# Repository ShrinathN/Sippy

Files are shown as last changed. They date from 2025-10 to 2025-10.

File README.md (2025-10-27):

# Sippy
A device which will remind me to drink water. Pretty cool. Uses accelerometer data to predict when, and how much water was drank. Needs the geometry of the bottle it is mounted on to work. WIP.

## Assembled
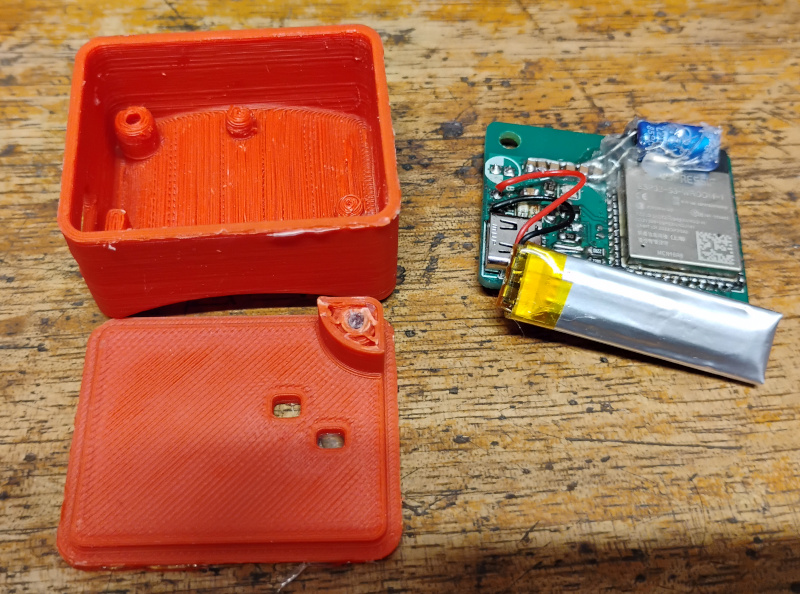
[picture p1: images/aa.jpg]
device

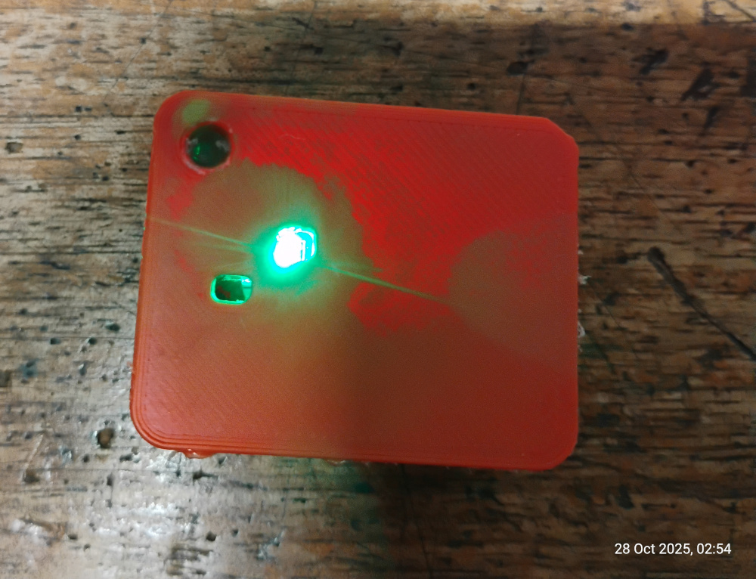
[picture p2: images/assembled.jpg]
assem

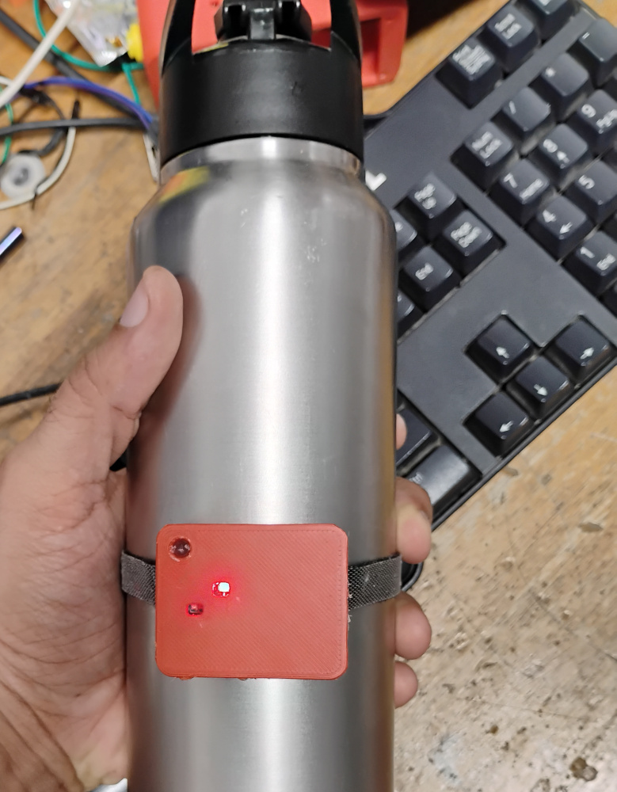
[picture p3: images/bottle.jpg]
bottle


## Images of the board
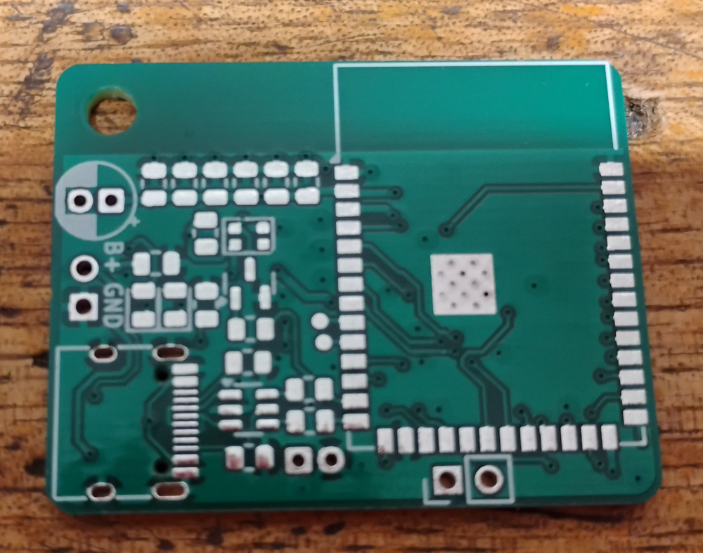
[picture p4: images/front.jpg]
front

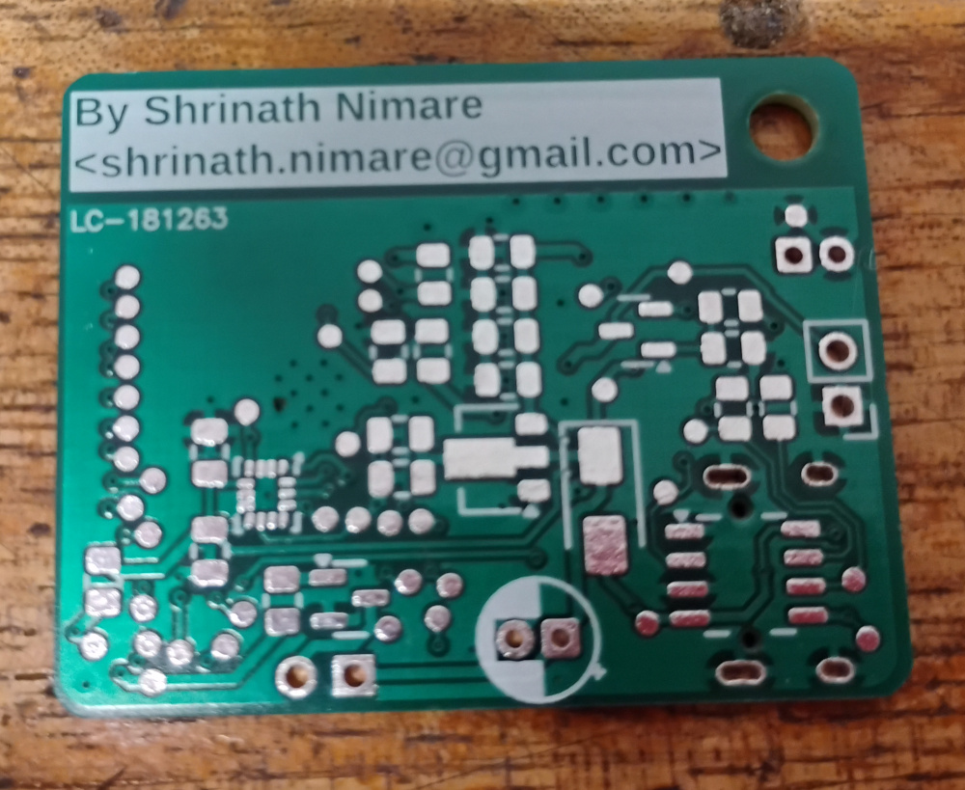
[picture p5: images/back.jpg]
back


## Images of the enclosure
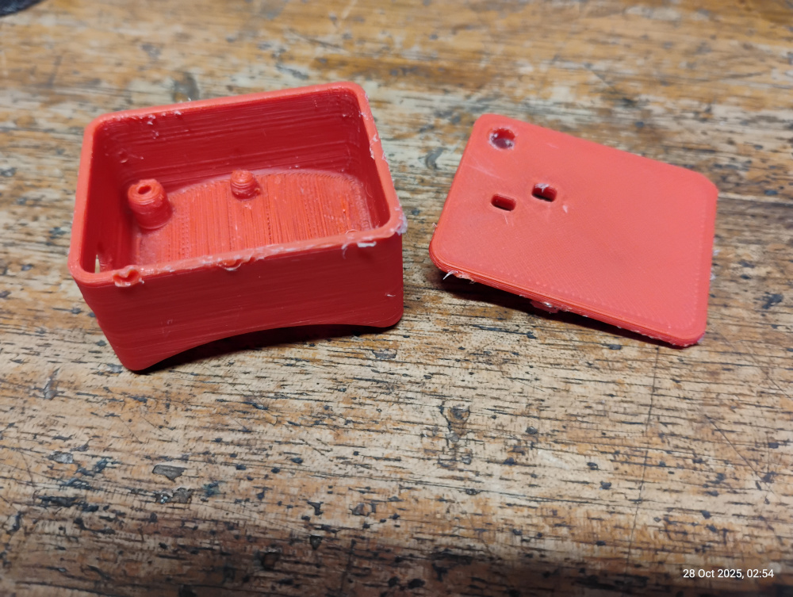
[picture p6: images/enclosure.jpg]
enclosure1

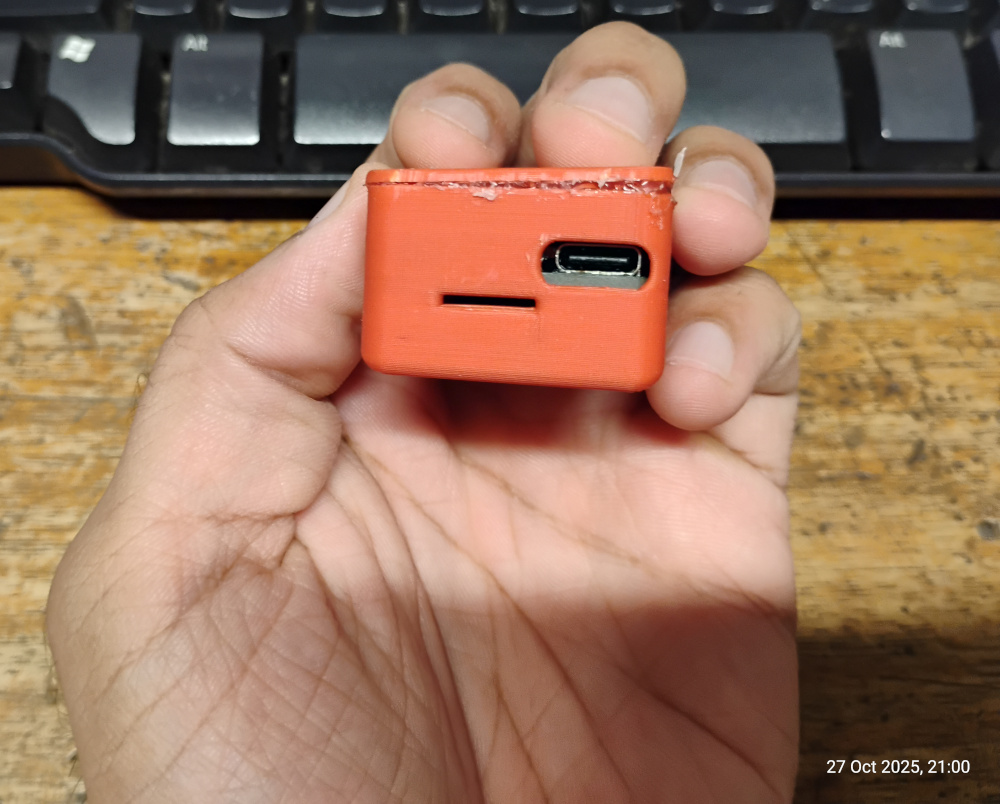
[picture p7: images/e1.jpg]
enclosure2

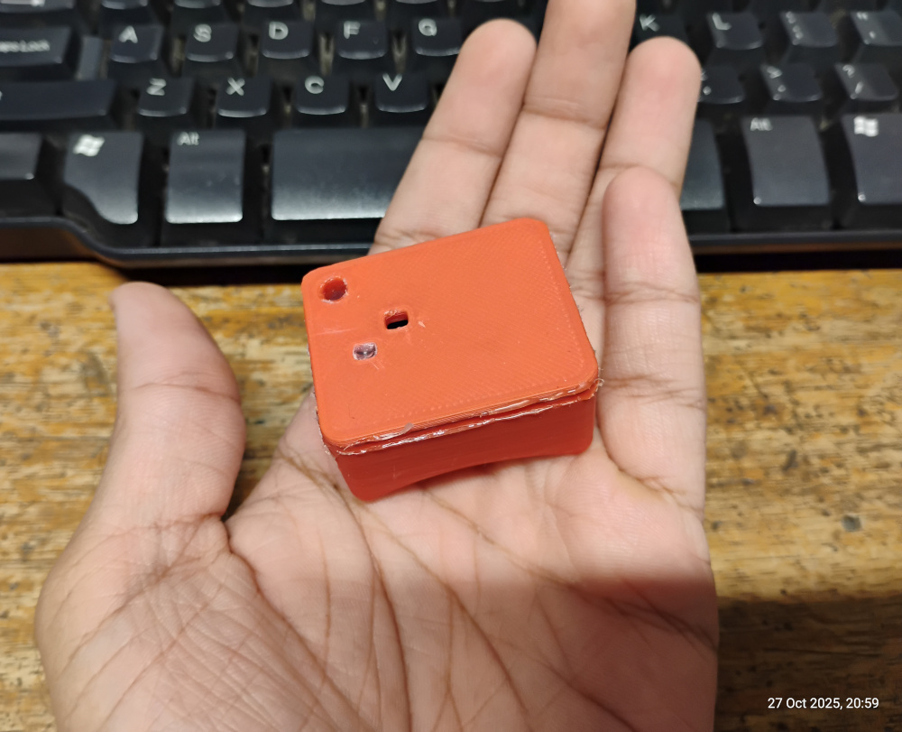
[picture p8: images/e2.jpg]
enclosure3


## Renders of the PCB
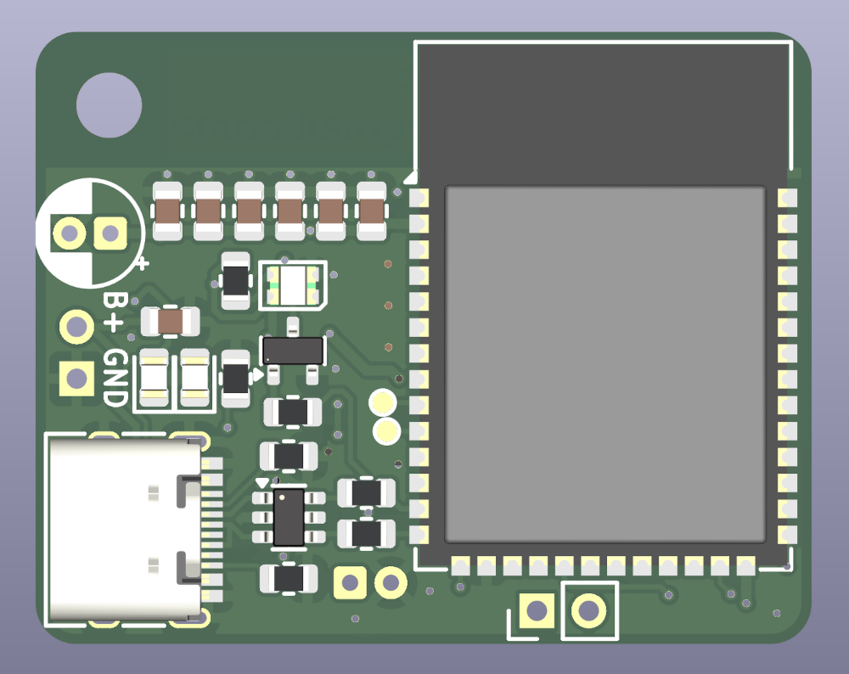
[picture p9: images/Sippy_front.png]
front

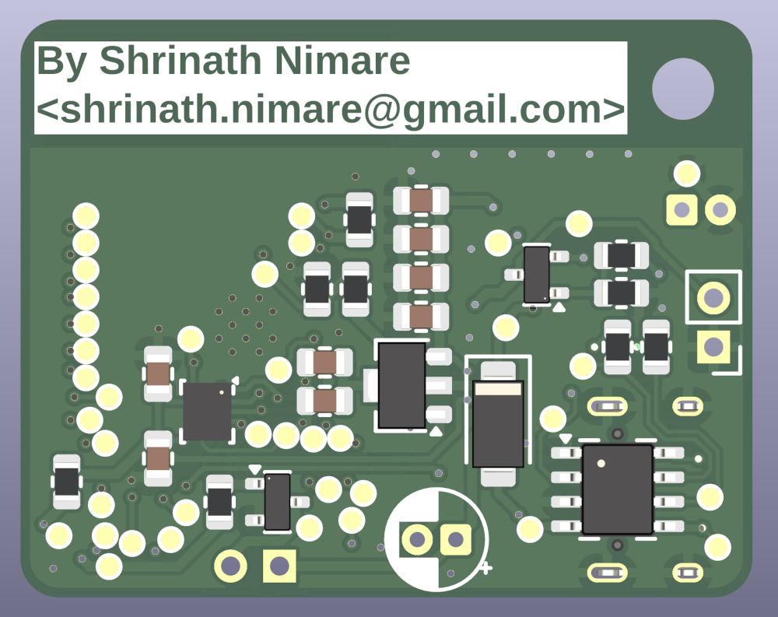
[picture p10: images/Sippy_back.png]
back


## Renders of the enclosure
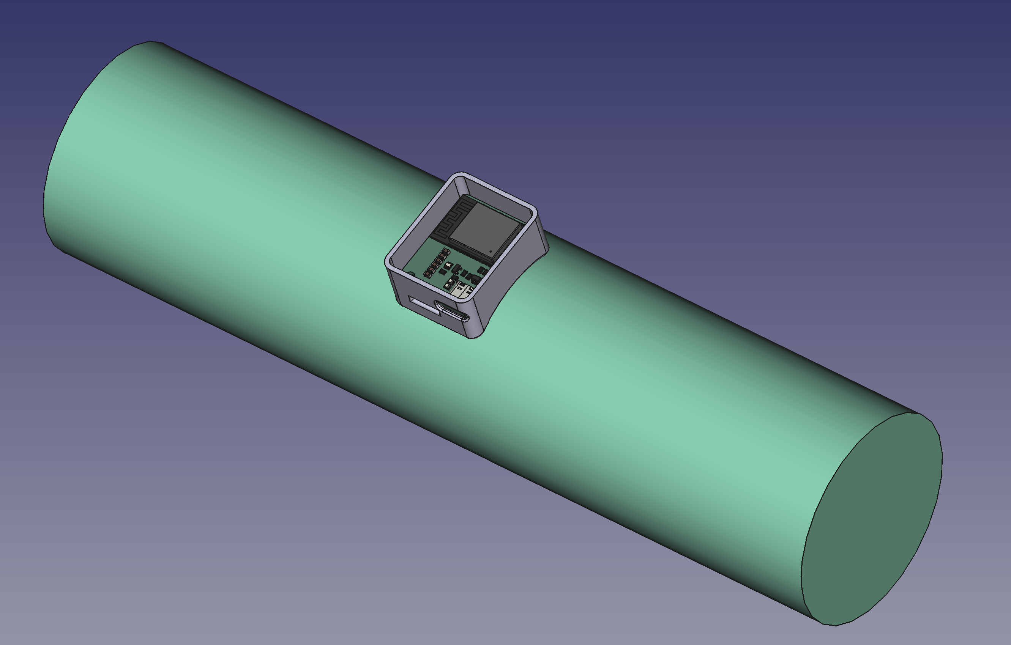
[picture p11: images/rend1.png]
rend1

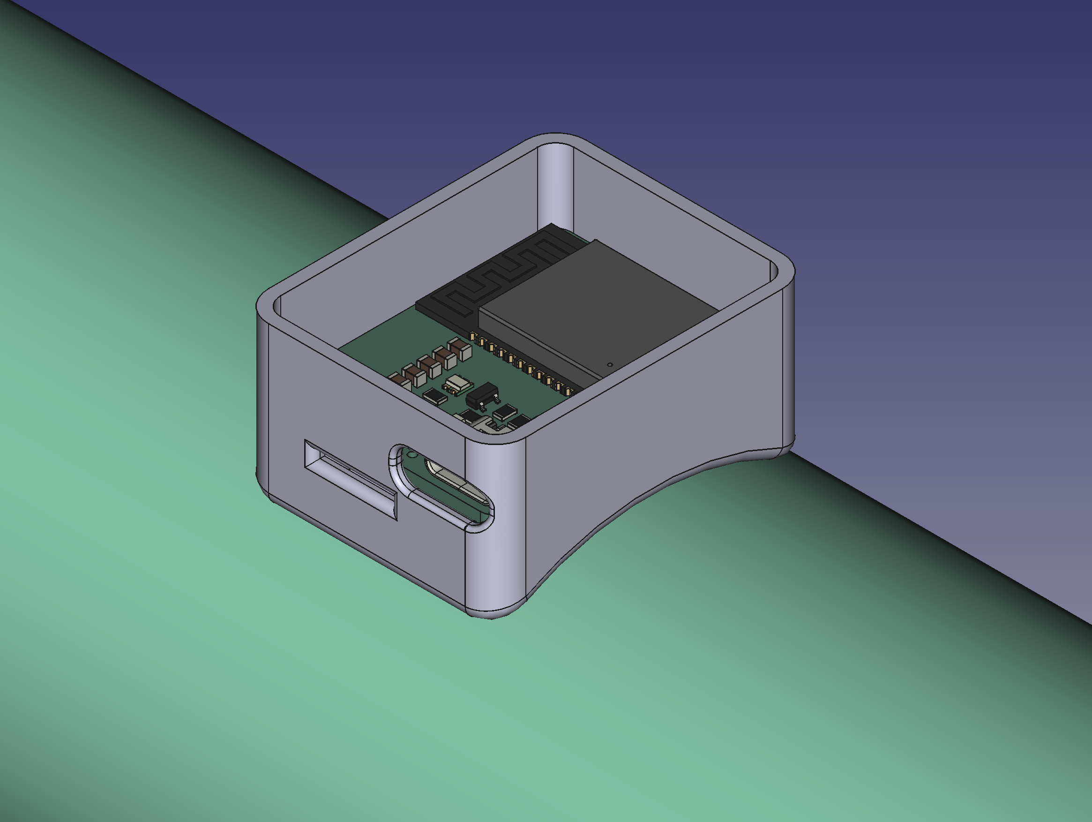
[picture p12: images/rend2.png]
rend2

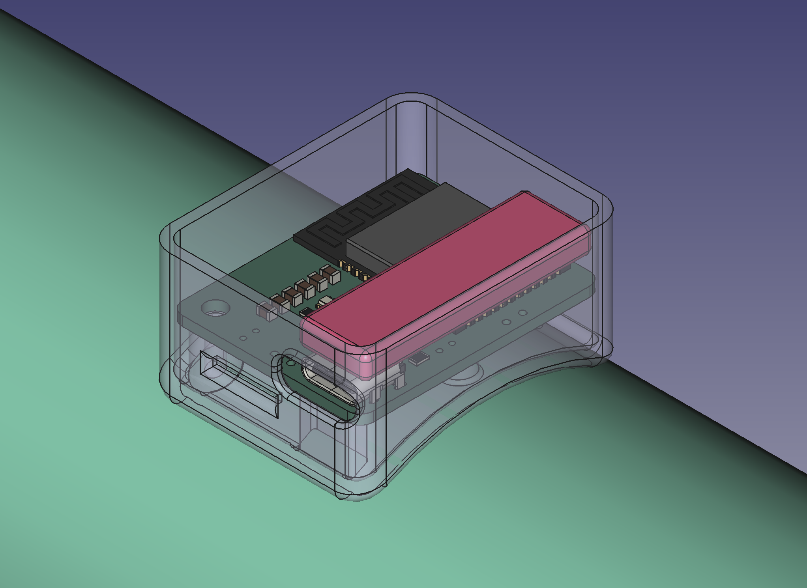
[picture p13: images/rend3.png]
rend3

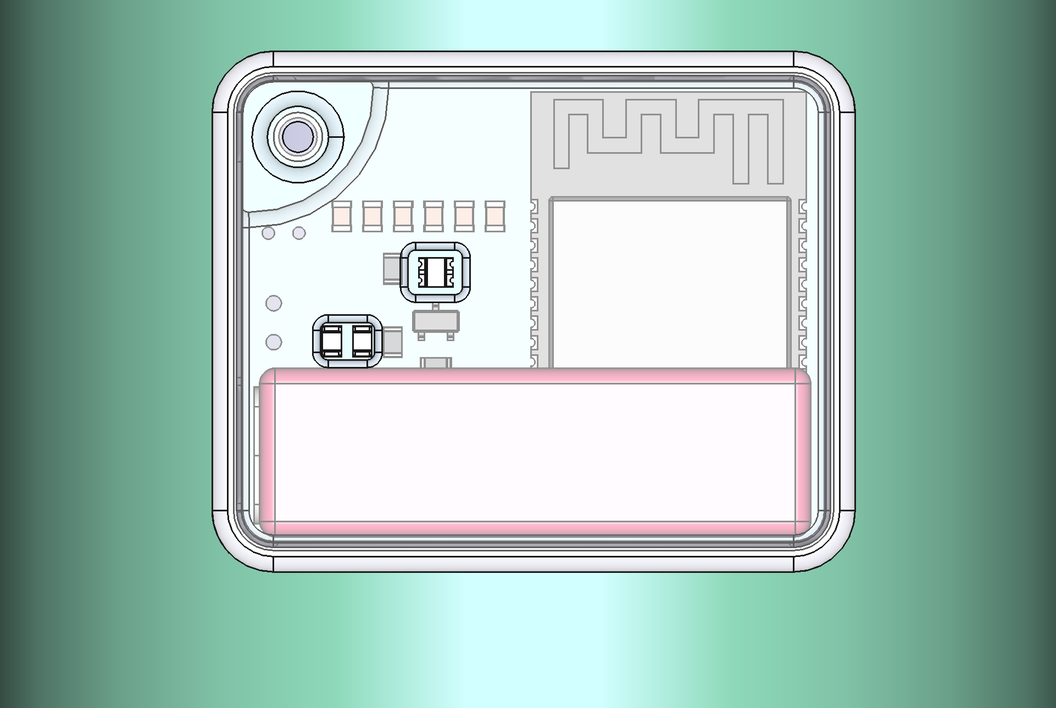
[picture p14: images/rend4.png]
rend4


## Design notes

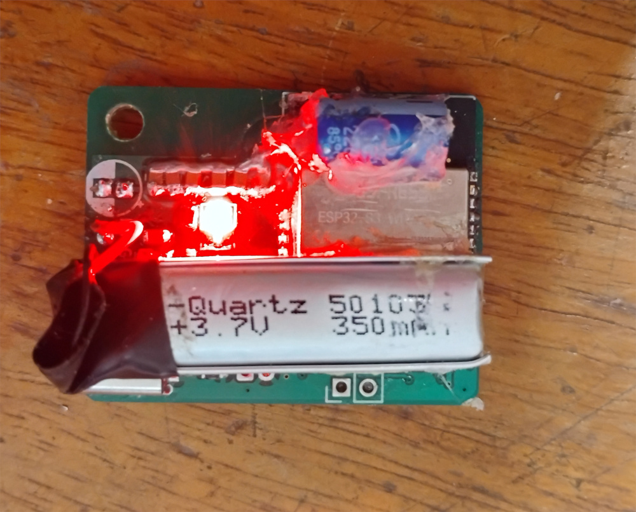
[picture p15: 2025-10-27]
images/device.jpg

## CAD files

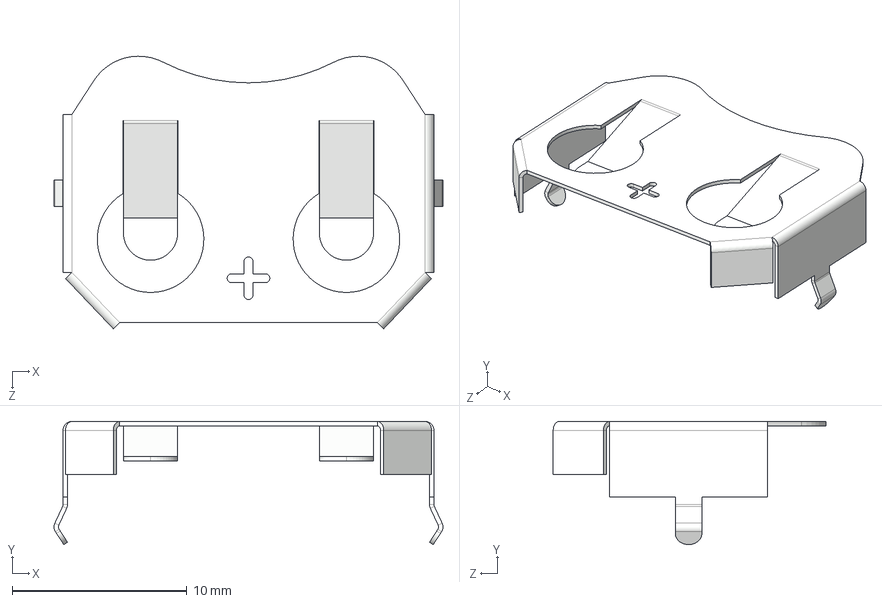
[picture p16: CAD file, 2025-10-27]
Custom Parts/3D Models/keystone-PN3035.STEP
22.2 x 7.04 x 15.6 mm

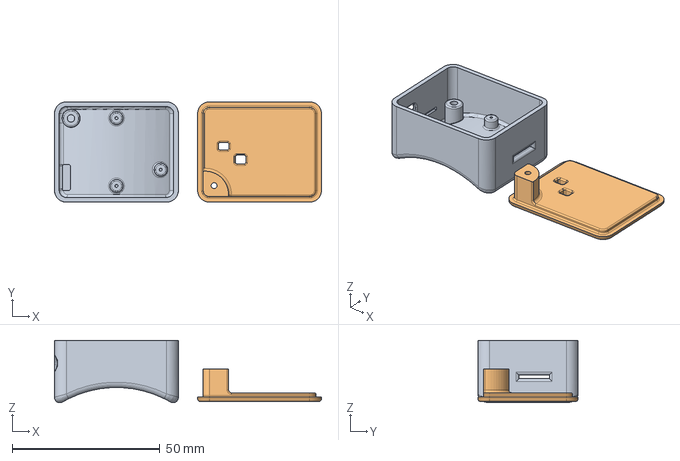
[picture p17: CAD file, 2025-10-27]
Enclosure/Enclosure.step
90.5 x 34.0 x 21.2 mm
Hole001

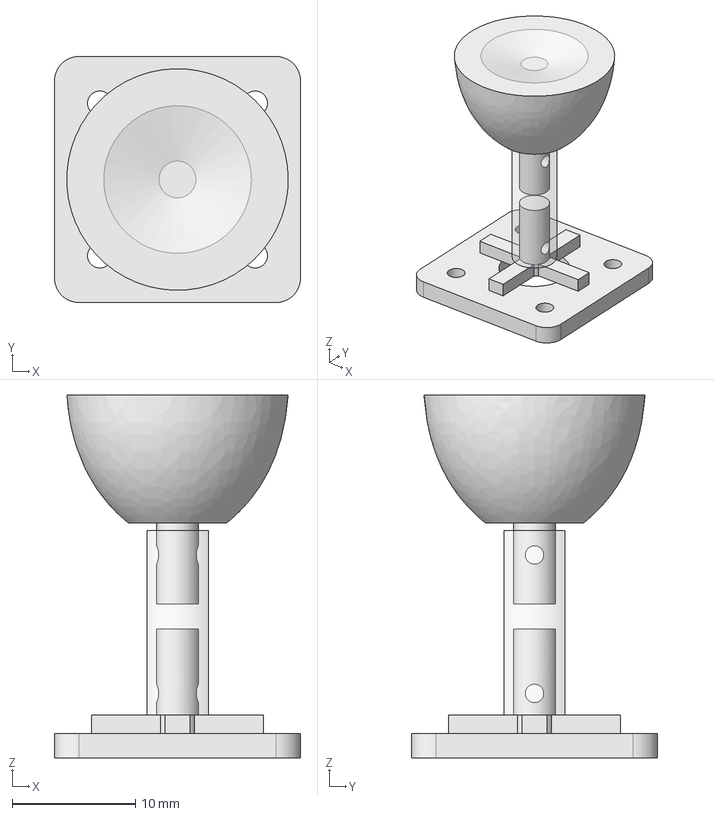
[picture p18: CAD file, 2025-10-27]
Custom Parts/3D Models/heheboy.step
20.0 x 20.0 x 29.5 mm
Deflector_Body
Spring_Body

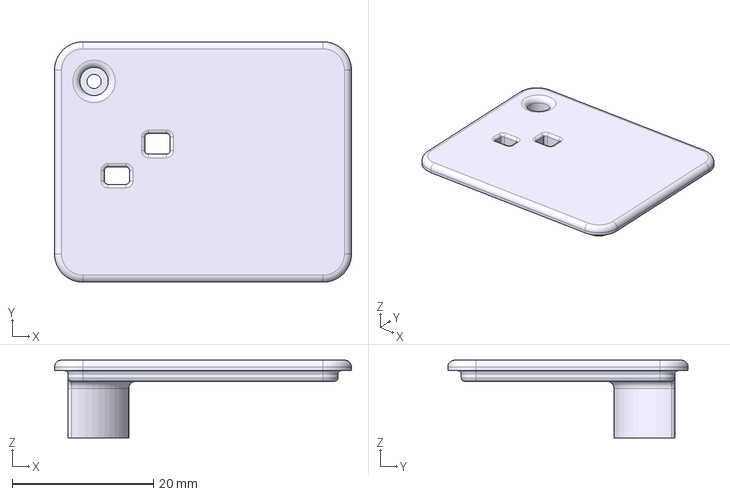
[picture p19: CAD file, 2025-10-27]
Enclosure/Sippy_Enclosure-SippyEnclosureTopFillet014.step
42.0 x 34.0 x 11.0 mm

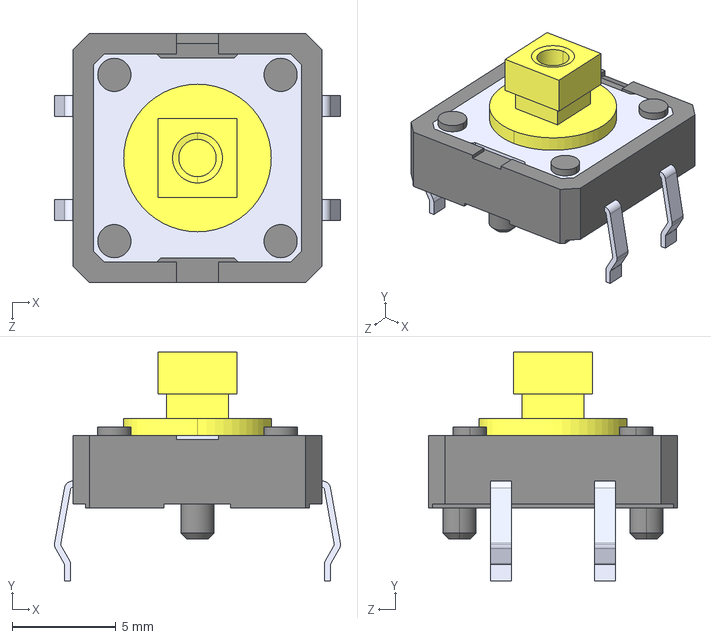
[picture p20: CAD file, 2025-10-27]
Custom Parts/3D Models/B3F-4055--3DModel-STEP-418109.STEP
13.8 x 11.0 x 12.0 mm

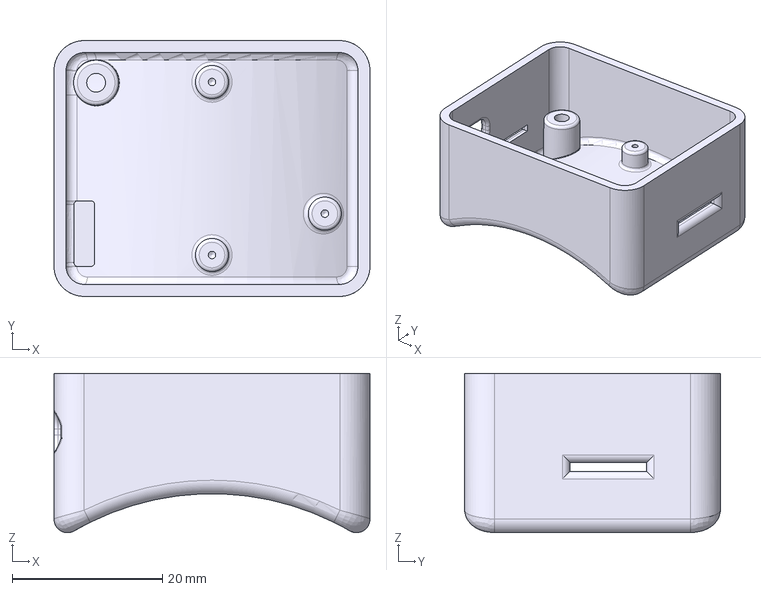
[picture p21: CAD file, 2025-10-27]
Enclosure/Sippy_Enclosure-SippyEnclosureBottomHole001.step
42.0 x 34.0 x 21.2 mm

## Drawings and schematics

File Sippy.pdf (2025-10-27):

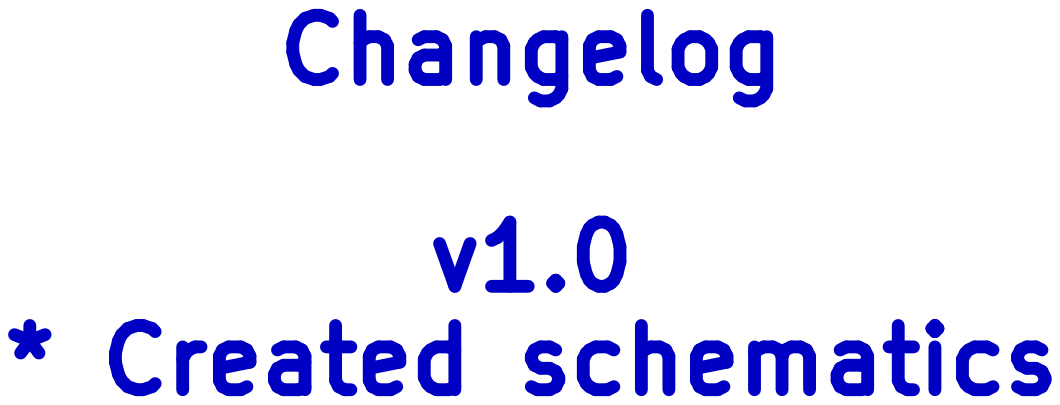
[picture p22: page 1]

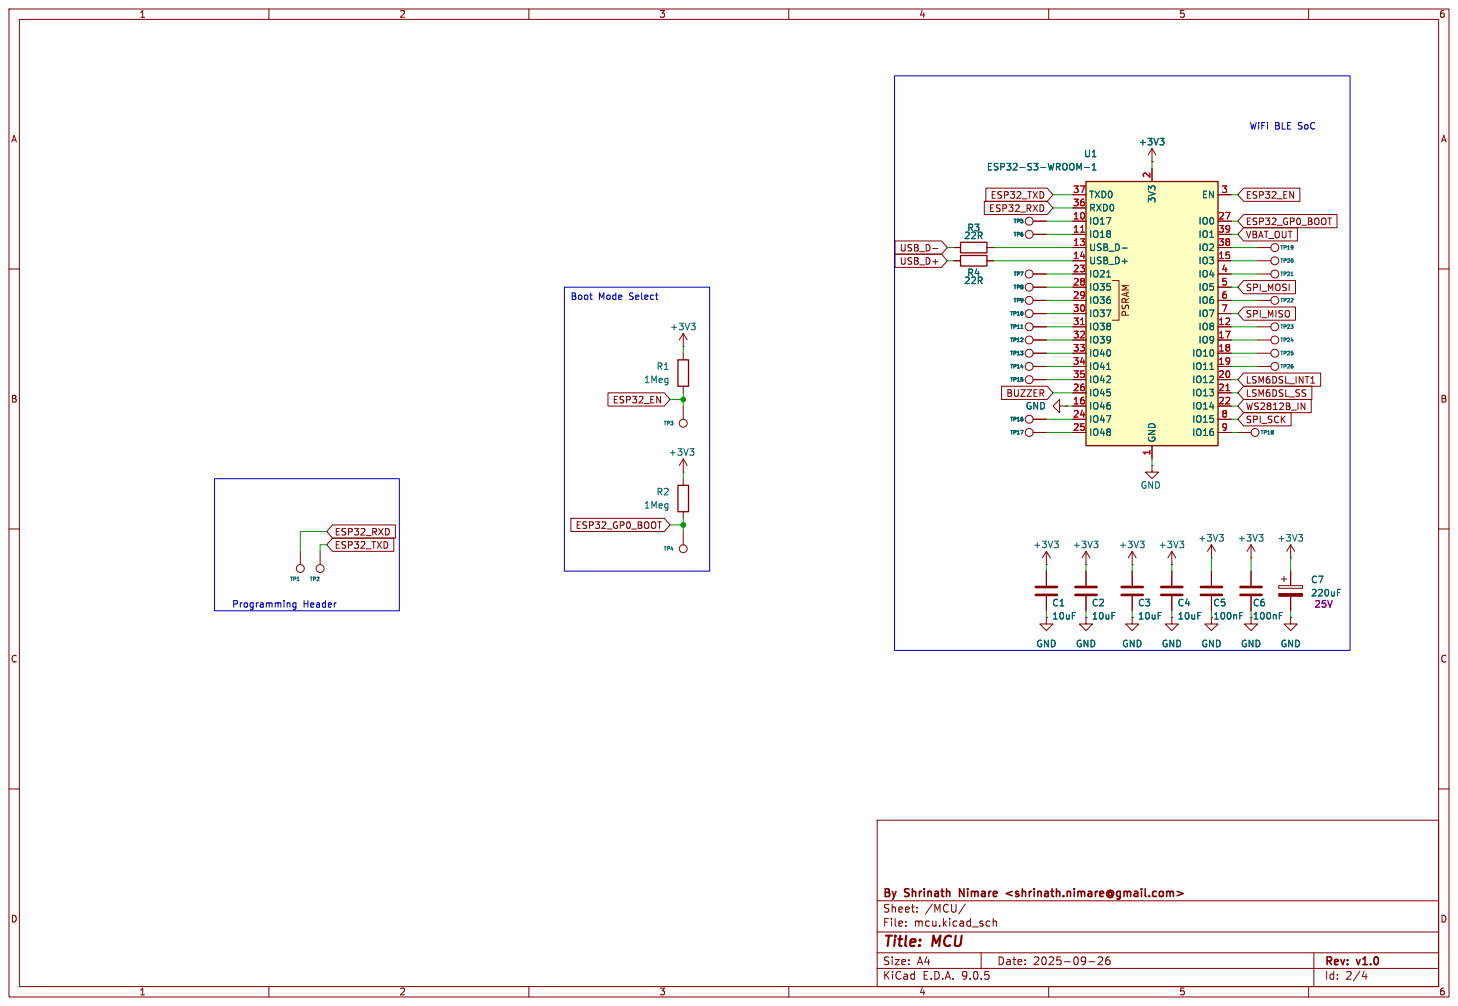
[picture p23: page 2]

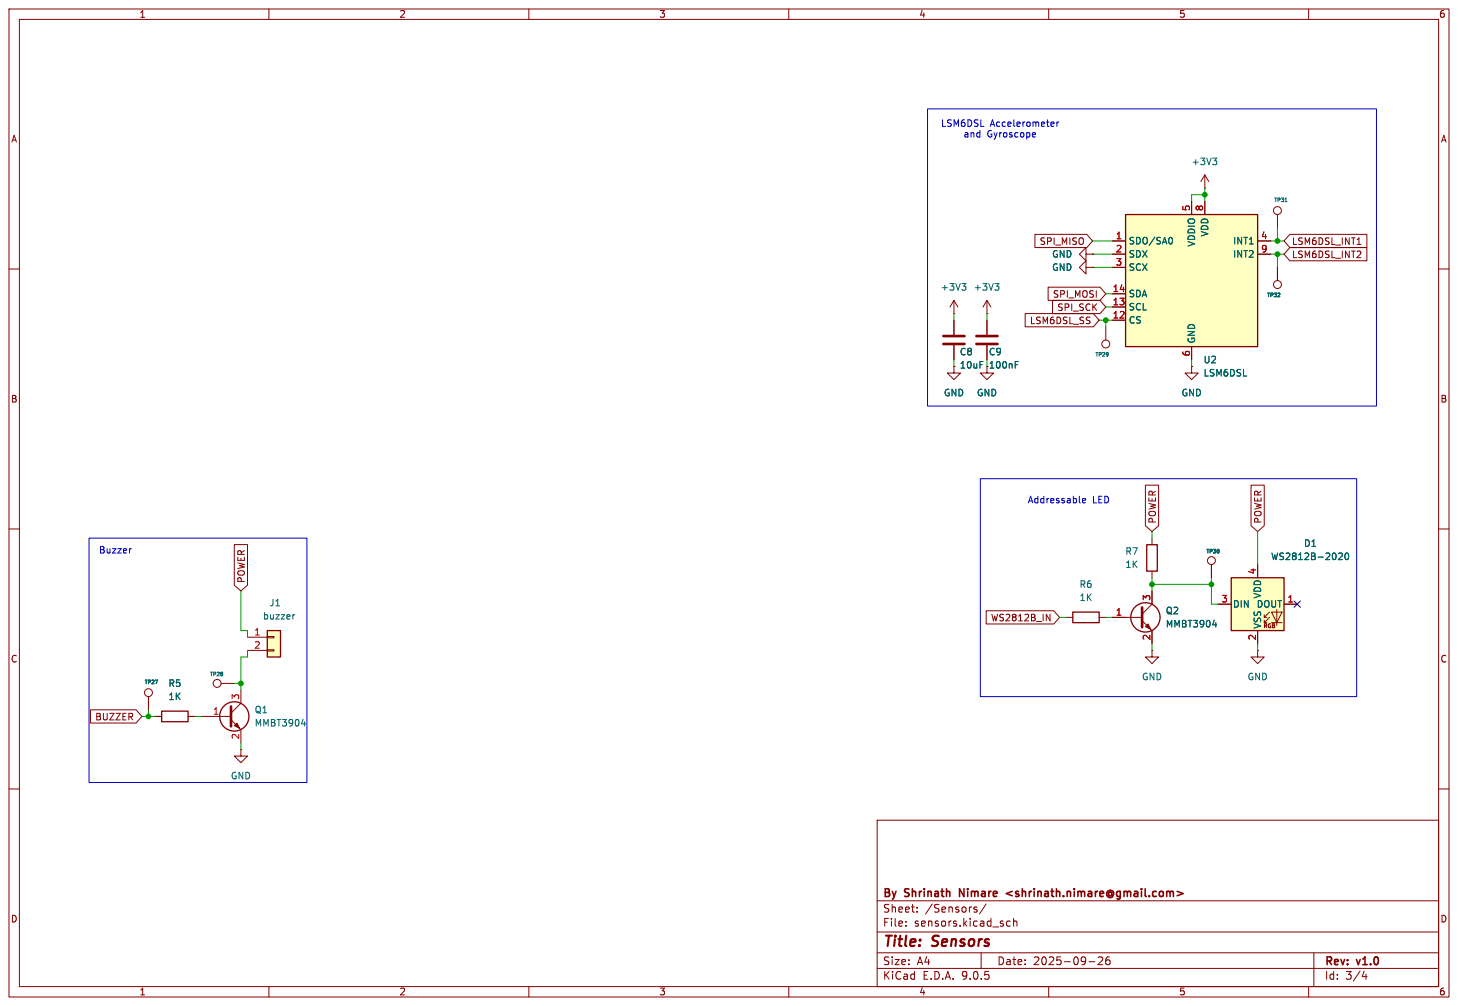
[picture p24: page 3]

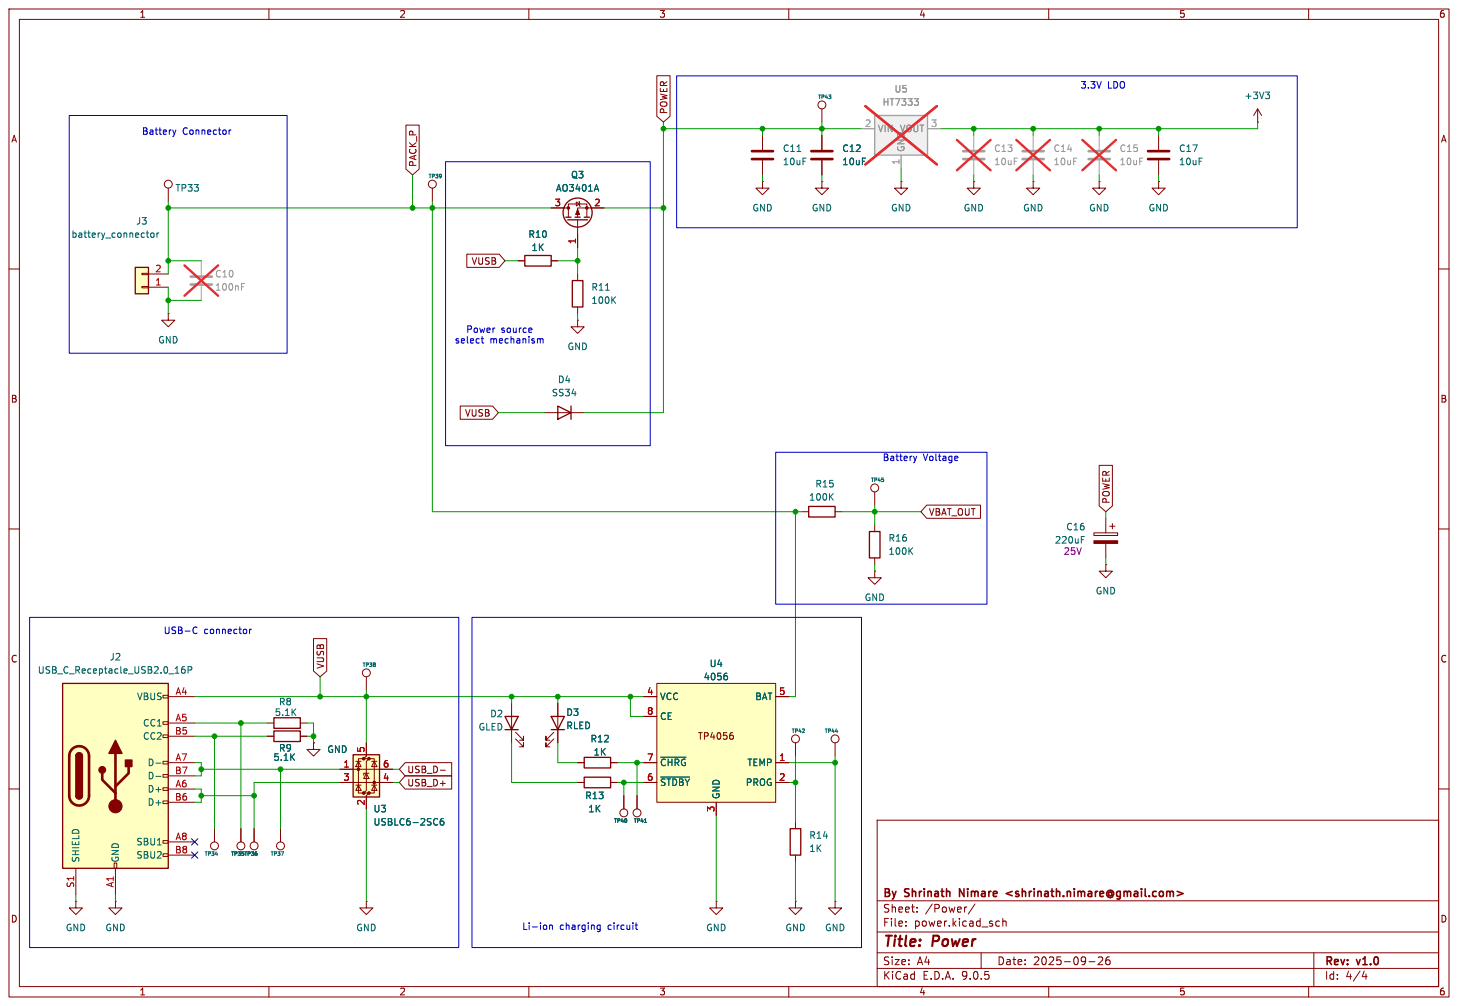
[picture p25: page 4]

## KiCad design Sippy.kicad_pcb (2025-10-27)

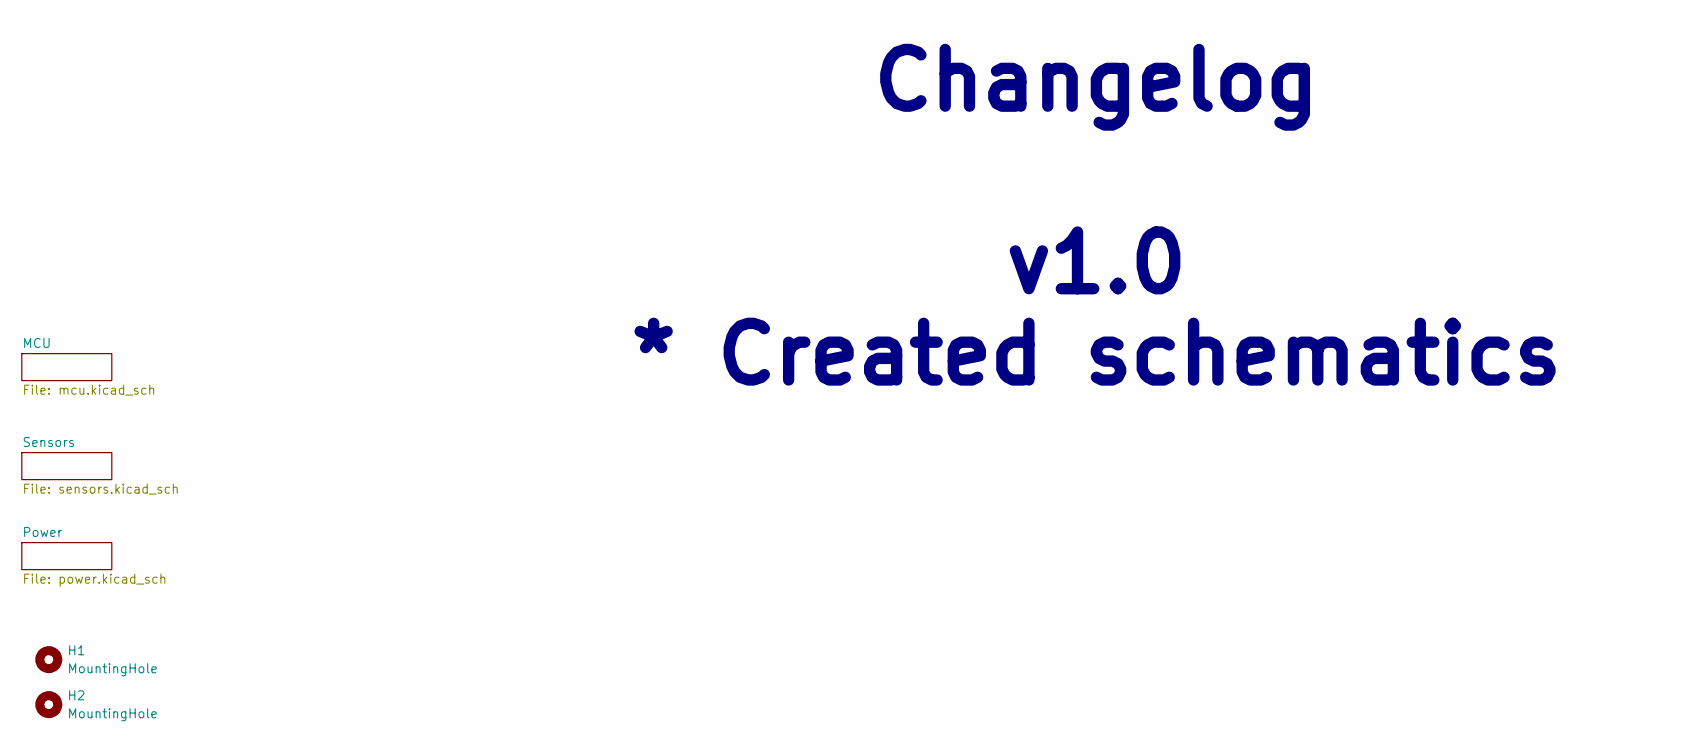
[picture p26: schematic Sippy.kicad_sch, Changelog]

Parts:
H1, H2: MountingHole; MountingHole_3.2mm_M3

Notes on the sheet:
Changelog v1.0 * Created schematics

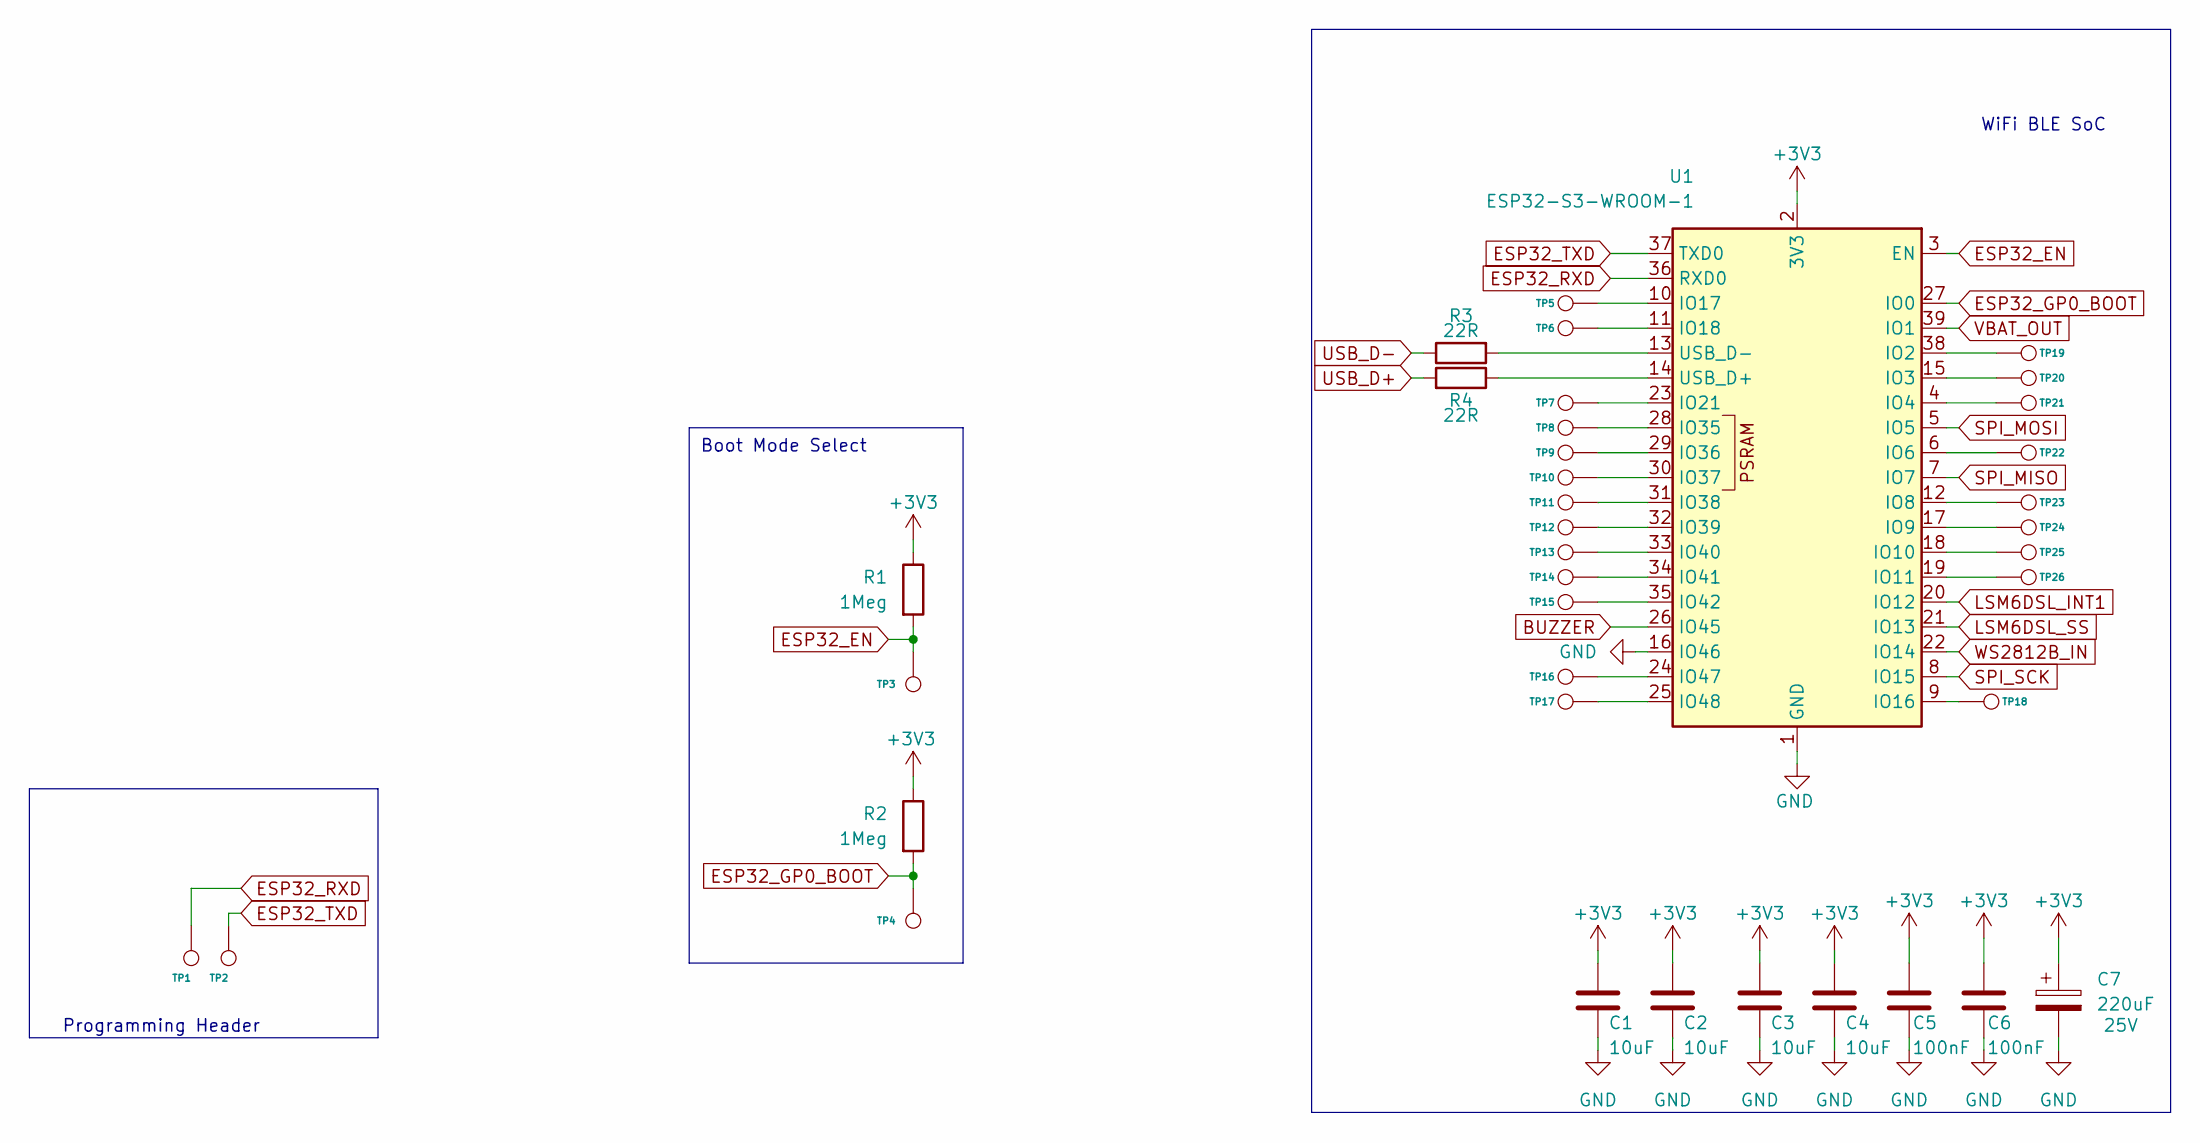
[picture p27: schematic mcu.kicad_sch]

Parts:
C1, C2, C3, C4: 10uF; C_0805_2012Metric
C5, C6: 100nF; C_0805_2012Metric
C7: 220uF; CP_Radial_D5.0mm_P2.00mm; Rating 25V
R1, R2: 1Meg; R_0805_2012Metric
R3, R4: 22R; R_0805_2012Metric
TP1, TP2, TP3, TP4, TP5, TP6, TP7, TP8, TP9, TP10, TP11, TP12, TP13, TP14, TP15, TP16, TP17, TP18, TP19, TP20, TP21, TP22, TP23, TP24, TP25, TP26: TestPoint; TestPoint_Pad_D1.0mm_small
U1: ESP32-S3-WROOM-1

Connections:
+3V3: C1.2, C2.2, C3.2, C4.2, C5.2, C6.2, C7.1, R1.1, R2.1, U1.2 (3V3); also elsewhere on the board
BUZZER: U1.26 (IO45); also elsewhere on the board
ESP32_EN: R1.2, TP3.1, U1.3 (EN)
ESP32_GP0_BOOT: R2.2, TP4.1, U1.27 (IO0)
ESP32_RXD: TP1.1, U1.36 (RXD0)
ESP32_TXD: TP2.1, U1.37 (TXD0)
GND: C1.1, C2.1, C3.1, C4.1, C5.1, C6.1, C7.2, U1.1 (GND), U1.16 (IO46), U1.40 (GND), U1.41 (GND); also elsewhere on the board
LSM6DSL_INT1: U1.20 (IO12); also elsewhere on the board
LSM6DSL_SS: U1.21 (IO13); also elsewhere on the board
unnamed: TP19.1, U1.38 (IO2)
unnamed: TP20.1, U1.15 (IO3)
unnamed: TP21.1, U1.4 (IO4)
unnamed: TP22.1, U1.6 (IO6)
unnamed: TP23.1, U1.12 (IO8)
unnamed: TP24.1, U1.17 (IO9)
unnamed: TP25.1, U1.18 (IO10)
unnamed: TP26.1, U1.19 (IO11)
unnamed: TP18.1, U1.9 (IO16)
unnamed: TP5.1, U1.10 (IO17)
unnamed: TP6.1, U1.11 (IO18)
unnamed: TP7.1, U1.23 (IO21)
unnamed: TP8.1, U1.28 (IO35)
unnamed: TP9.1, U1.29 (IO36)
unnamed: TP10.1, U1.30 (IO37)
unnamed: TP11.1, U1.31 (IO38)
unnamed: TP12.1, U1.32 (IO39)
unnamed: TP13.1, U1.33 (IO40)
unnamed: TP14.1, U1.34 (IO41)
unnamed: TP15.1, U1.35 (IO42)
unnamed: TP16.1, U1.24 (IO47)
unnamed: TP17.1, U1.25 (IO48)
unnamed: R4.1, U1.14 (USB_D+)
unnamed: R3.2, U1.13 (USB_D-)
SPI_MISO: U1.7 (IO7); also elsewhere on the board
SPI_MOSI: U1.5 (IO5); also elsewhere on the board
SPI_SCK: U1.8 (IO15); also elsewhere on the board
USB_D+: R4.2; also elsewhere on the board
USB_D-: R3.1; also elsewhere on the board
VBAT_OUT: U1.39 (IO1); also elsewhere on the board
WS2812B_IN: U1.22 (IO14); also elsewhere on the board

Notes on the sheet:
Boot Mode Select
WiFi BLE SoC
Programming Header

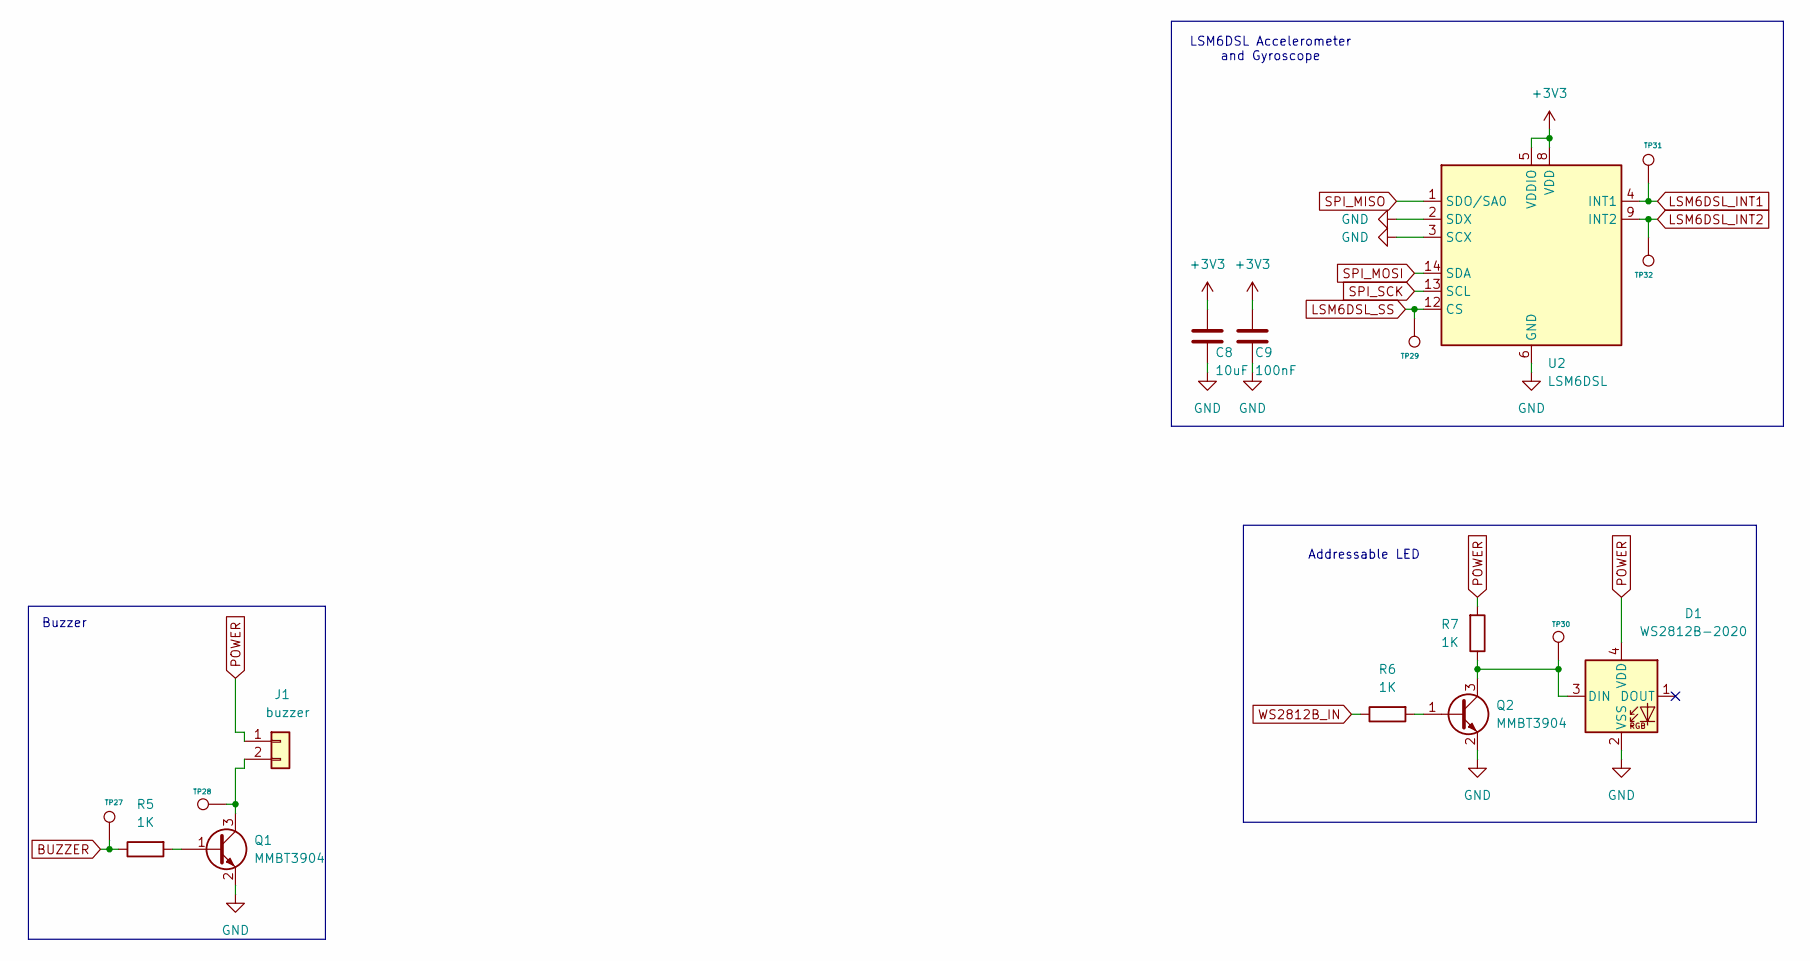
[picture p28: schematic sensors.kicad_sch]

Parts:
C8: 10uF; C_0805_2012Metric
C9: 100nF; C_0805_2012Metric
D1: WS2812B-2020; LED_WS2812B-2020_PLCC4_2.0x2.0mm
J1: buzzer; PinHeader_1x02_P2.54mm_Vertical
Q1, Q2: MMBT3904; SOT-23
R5, R6, R7: 1K; R_0805_2012Metric
TP27, TP28, TP29, TP30, TP31, TP32: TestPoint; TestPoint_Pad_D1.0mm_small
U2: LSM6DSL; LGA-14_3x2.5mm_P0.5mm_LayoutBorder3x4y

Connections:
+3V3: C8.2, C9.2, U2.5 (VDDIO), U2.8 (VDD); also elsewhere on the board
BUZZER: R5.1, TP27.1; also elsewhere on the board
GND: C8.1, C9.1, D1.2 (VSS), Q1.2 (E), Q2.2 (E), U2.2 (SDX), U2.3 (SCX), U2.6 (GND), U2.7 (GND); also elsewhere on the board
LSM6DSL_INT1: TP31.1, U2.4 (INT1); also elsewhere on the board
LSM6DSL_INT2: TP32.1, U2.9 (INT2)
LSM6DSL_SS: TP29.1, U2.12 (CS); also elsewhere on the board
unnamed: D1.3 (DIN), Q2.3 (C), R7.1, TP30.1
unnamed: J1.2, Q1.3 (C), TP28.1
unnamed: Q1.1 (B), R5.2
unnamed: Q2.1 (B), R6.2
POWER: D1.4 (VDD), J1.1, R7.2; also elsewhere on the board
SPI_MISO: U2.1 (SDO/SA0); also elsewhere on the board
SPI_MOSI: U2.14 (SDA); also elsewhere on the board
SPI_SCK: U2.13 (SCL); also elsewhere on the board
WS2812B_IN: R6.1; also elsewhere on the board

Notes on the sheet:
Addressable LED
Buzzer
LSM6DSL Accelerometer and Gyroscope

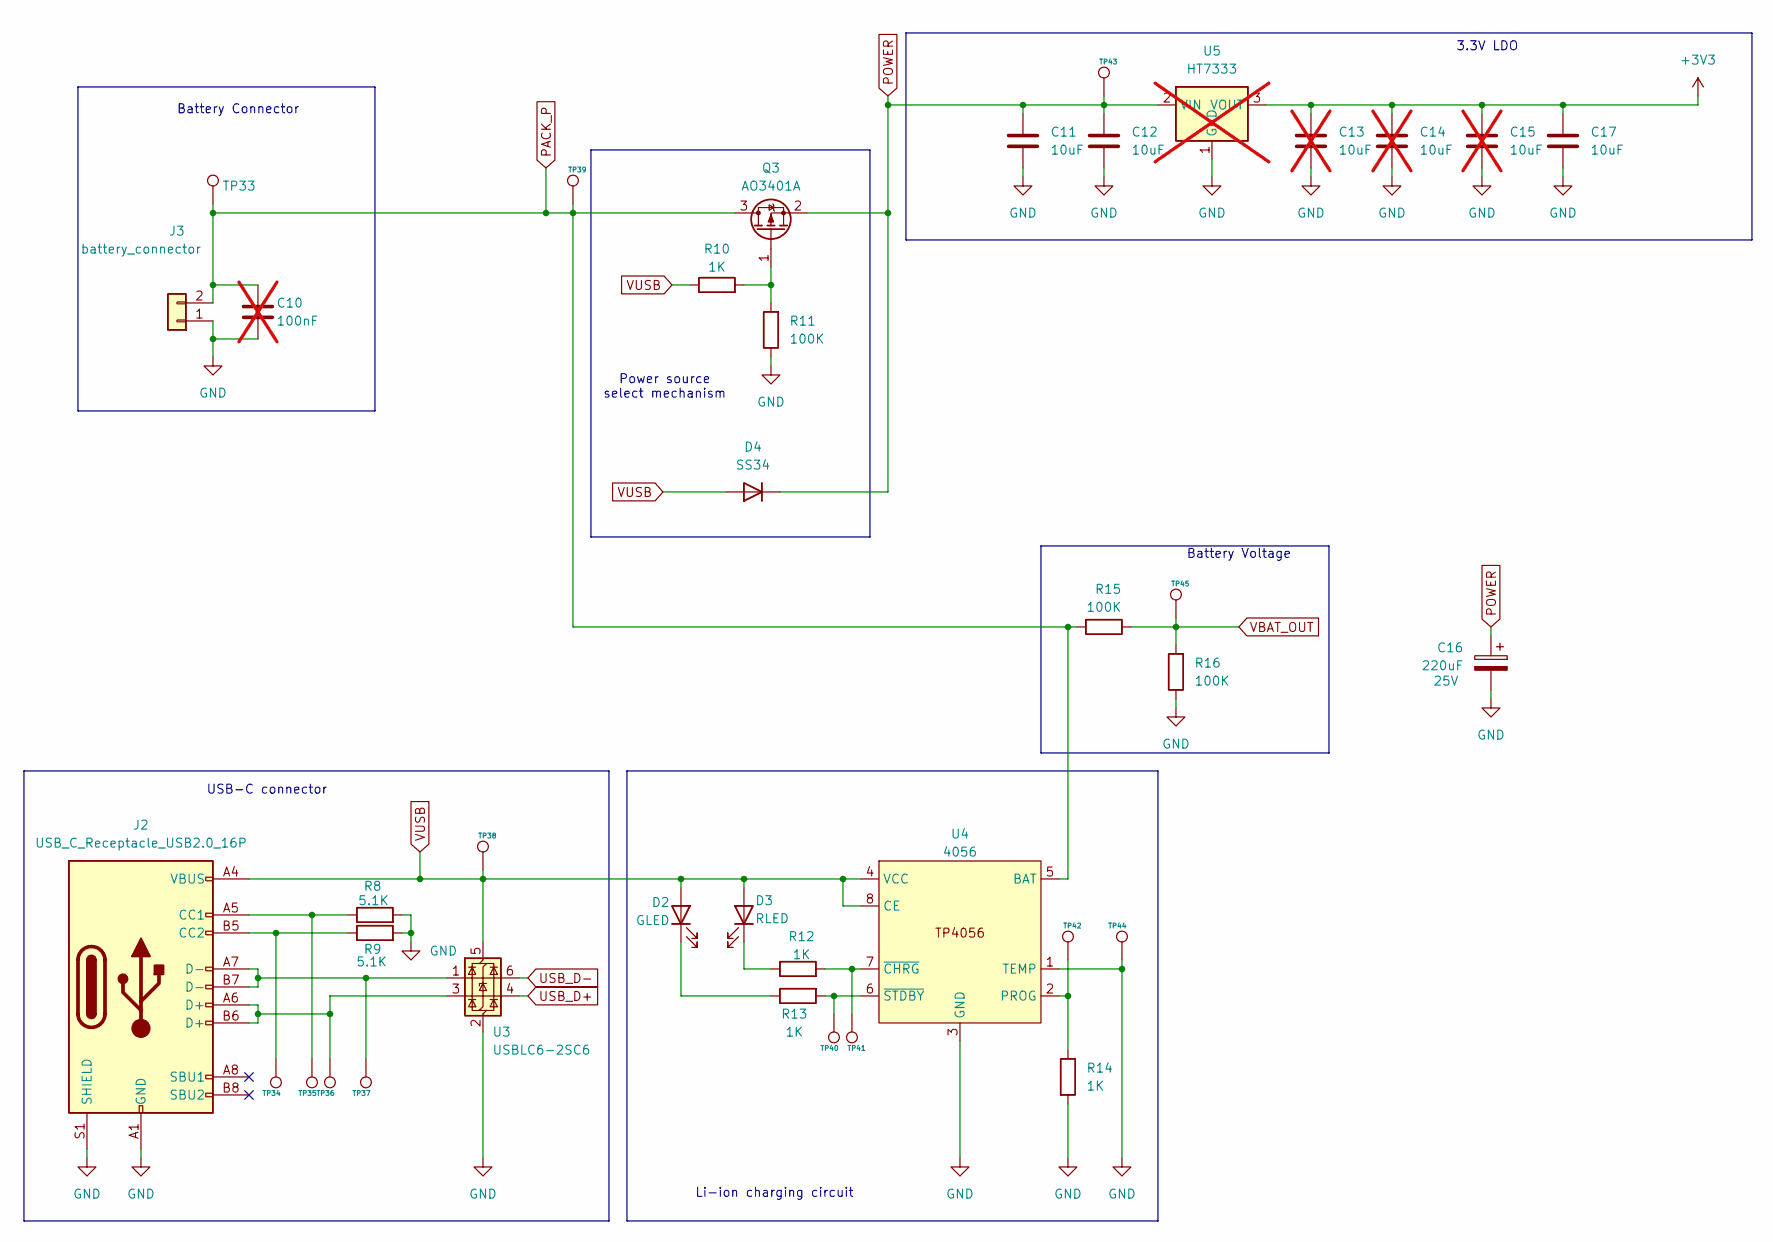
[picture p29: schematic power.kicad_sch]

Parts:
C10: 100nF; C_0805_2012Metric; not fitted
C11, C12, C17: 10uF; C_0805_2012Metric
C13, C14, C15: 10uF; C_0805_2012Metric; not fitted
C16: 220uF; CP_Radial_D5.0mm_P2.00mm; Rating 25V
D2: GLED; LED_0805_2012Metric
D3: RLED; LED_0805_2012Metric
D4: SS34; D_SMA
J2: USB_C_Receptacle_USB2.0_16P; USB_C_Receptacle_HRO_TYPE-C-31-M-12
J3: battery_connector; PinHeader_1x02_P2.54mm_Vertical
Q3: AO3401A; SOT-23
R8, R9: 5.1K; R_0805_2012Metric
R10, R12, R13, R14: 1K; R_0805_2012Metric
R11, R15, R16: 100K; R_0805_2012Metric
TP33, TP34, TP35, TP36, TP37, TP38, TP39, TP40, TP41, TP42, TP43, TP44, TP45: TestPoint; TestPoint_Pad_D1.0mm_small
U3: USBLC6-2SC6; SOT-23-6
U4: 4056; SOP-8_3.9x4.9mm_P1.27mm
U5: HT7333; SOT-89-3; not fitted

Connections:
+3V3: C13.1, C14.1, C15.1, C17.1, U5.3 (VOUT); also elsewhere on the board
GND: C10.2, C11.2, C12.2, C13.2, C14.2, C15.2, C16.2, C17.2, J2.A1 (GND), J2.A12 (GND), J2.B1 (GND), J2.B12 (GND), J2.S1 (SHIELD), J3.1, R8.2, R9.2, R11.1, R14.2, R16.1, TP44.1, U3.2 (GND), U4.1 (TEMP), U4.3 (GND), U5.1 (GND); also elsewhere on the board
unnamed: D2.1 (K), R13.1
unnamed: D3.1 (K), R12.1
unnamed: J2.A5 (CC1), R8.1, TP35.1
unnamed: J2.B5 (CC2), R9.1, TP34.1
unnamed: J2.A6 (D+), J2.B6 (D+), TP36.1, U3.3 (I/O2)
unnamed: J2.A7 (D-), J2.B7 (D-), TP37.1, U3.1 (I/O1)
unnamed: Q3.1 (G), R10.2, R11.2
unnamed: R14.1, TP42.1, U4.2 (PROG)
unnamed: R12.2, TP41.1, U4.7 (~CHRG)
unnamed: R13.2, TP40.1, U4.6 (~STDBY)
PACK_P: C10.1, J3.2, Q3.3 (D), R15.2, TP33.1, TP39.1, U4.5 (BAT)
POWER: C11.1, C12.1, C16.1, D4.1 (K), Q3.2 (S), TP43.1, U5.2 (VIN); also elsewhere on the board
USB_D+: U3.4 (I/O2); also elsewhere on the board
USB_D-: U3.6 (I/O1); also elsewhere on the board
VBAT_OUT: R15.1, R16.2, TP45.1; also elsewhere on the board
VUSB: D2.2 (A), D3.2 (A), D4.2 (A), J2.A4 (VBUS), J2.A9 (VBUS), J2.B4 (VBUS), J2.B9 (VBUS), R10.1, TP38.1, U3.5 (VBUS), U4.4 (VCC), U4.8 (CE)

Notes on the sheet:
Battery Connector
Battery Voltage
3.3V LDO
USB-C connector
Li-ion charging circuit
Power source select mechanism

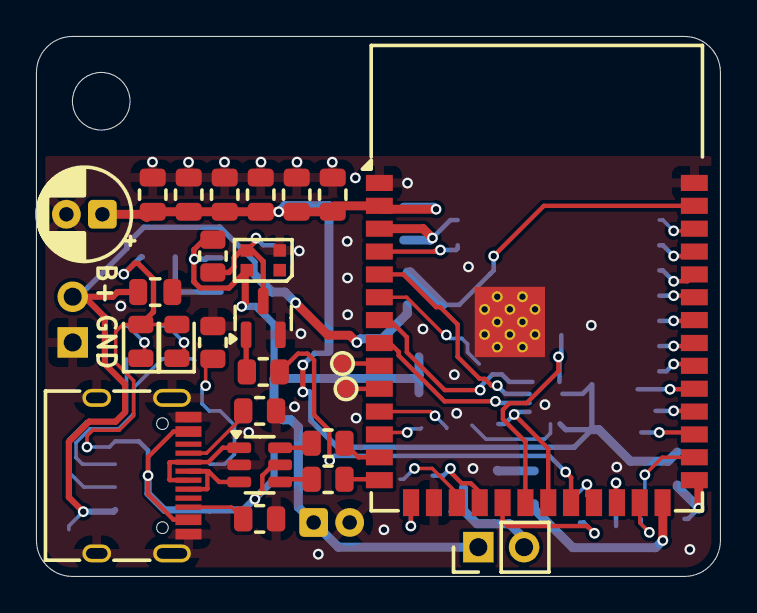
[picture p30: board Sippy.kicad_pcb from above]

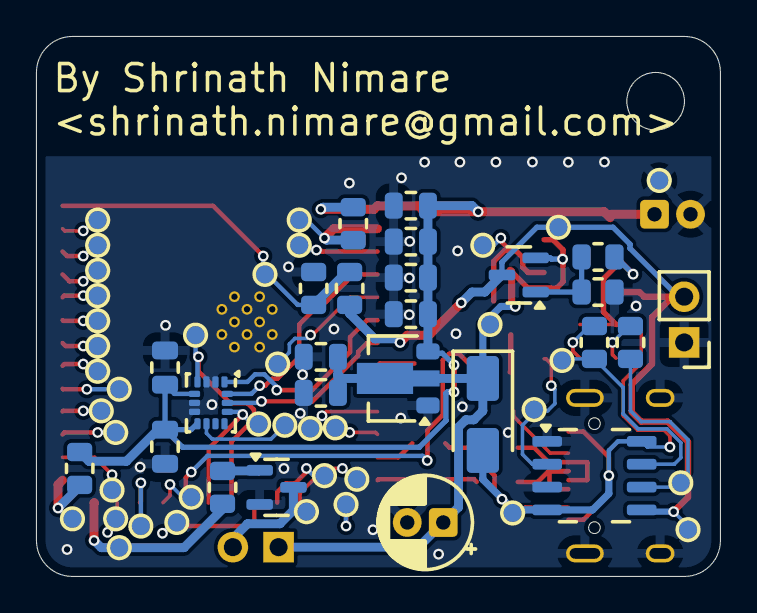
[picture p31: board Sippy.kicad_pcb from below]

Board: 2 copper layers, 38.0 x 30.0 mm, 90 parts (64 on the bottom side), 58 nets.

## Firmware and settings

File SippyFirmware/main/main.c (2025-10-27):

// transmitter
#include "main.h"
#include "sippy_init.h"
#include "sippy_wifi.h"
#include "LSM6DSL.h"
#include "ws2812b.h"

static const char *TAG = "example_main";

int app_main(void)
{
    // Change these to your wiring
    vTaskDelay(pdMS_TO_TICKS(1000));

    sippy_gpio_init();
    sippy_spi_init();
    vTaskDelay(100 / portTICK_PERIOD_MS);
    LSM6DSL_set_handle(get_lsm6dsl_handle(), get_spi_mutex());
    vTaskDelay(100 / portTICK_PERIOD_MS);
    LSM6DSL_Init();

    ws2812b_init();

    while (1)
    {
        for (uint8_t i = 0; i < 10; i++)
        {
            ws2812b_write(255,0,0);
            vTaskDelay(100 / portTICK_PERIOD_MS);
            // Off
            ws2812b_write(0, 0, 0);
            vTaskDelay(100 / portTICK_PERIOD_MS);
        }
        esp_deep_sleep((60 * 30) * 1000000ULL);
    }
}

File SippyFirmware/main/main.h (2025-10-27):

#ifndef MAIN_H
#define MAIN_H

// common SDK defines
#include <stdio.h>
#include "freertos/FreeRTOS.h"
#include "freertos/task.h"
#include "driver/gpio.h"
#include "esp_sleep.h"
#include "esp_log.h"
#include "nvs_flash.h"
#include "esp_system.h"
#include "esp_wifi.h"
#include "esp_event.h"
#include "esp_sleep.h"

#include "lwip/err.h"
#include "lwip/sys.h"

#include "driver/spi_master.h"
#include "driver/spi_common.h"
#include "esp_adc/adc_oneshot.h"
#include "esp_adc/adc_cali.h"
#include "esp_adc/adc_cali_scheme.h"
#include <stdlib.h>
#include <string.h>
#include "driver/rmt_tx.h"
#include "esp_err.h"

#include <sys/socket.h>
#include <sys/types.h>
#include <netinet/in.h>
#include "freertos/FreeRTOSConfig.h"
/* BLE */
#include "nimble/nimble_port.h"
#include "nimble/nimble_port_freertos.h"
#include "host/ble_hs.h"
#include "host/util/util.h"
#include "console/console.h"
#include "services/gatt/ble_svc_gatt.h"
#include "services/gap/ble_svc_gap.h"

// macros
#define ZEROS { \
    0,          \
}

// ADC pins
#define PIN_VBAT_OUT 1

//SPI Pins
#define PIN_SPI_MISO GPIO_NUM_7
#define PIN_SPI_MOSI GPIO_NUM_5
#define PIN_SPI_SCK GPIO_NUM_15
#define PIN_LSM6DSL_SS GPIO_NUM_13
#define PIN_LSM6DSL_INT1 GPIO_NUM_12
#define PIN_BUZZER GPIO_NUM_45
#define PIN_LED_DOUT GPIO_NUM_14

#endif

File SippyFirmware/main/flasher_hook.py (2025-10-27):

#!/usr/bin/env python3
import serial
import time
import os

PORT = "/dev/ttyACM0"
BAUD = 115200

def wait_for_device(port):
    print(f"Waiting for {port} to appear...")
    while not os.path.exists(port):
        time.sleep(0.1)
    print(f"{port} detected.")

def enter_bootloader(port, baud):
    print("Opening serial port...")
    with serial.Serial(port, baud, timeout=1) as ser:
        ser.rts = True
        ser.dtr = True
        time.sleep(0.1)

        # Step 3: Release reset (EN high)
        ser.dtr = False
        ser.rts = False
        time.sleep(0.1)

        ser.dtr = True
        ser.rts = True
        time.sleep(0.1)

        ser.dtr = False
        ser.rts = False
        time.sleep(0.1)

        print("ESP32 should now be in bootloader mode.")
        # Keep port open briefly to hold state

if __name__ == "__main__":
    wait_for_device(PORT)
    try:
        enter_bootloader(PORT, BAUD)
    except serial.SerialException as e:
        print(f"Serial error: {e}")
    print("Waiting for next wake-up...\n")
